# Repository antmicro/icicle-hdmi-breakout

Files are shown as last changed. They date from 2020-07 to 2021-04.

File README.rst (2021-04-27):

====================
Icicle HDMI breakout
====================

Copyright (c) 2020 `Antmicro <https://www.antmicro.com>`_

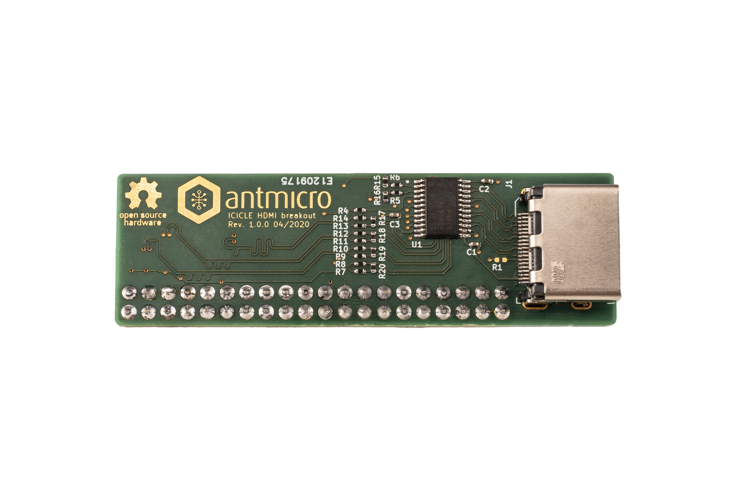
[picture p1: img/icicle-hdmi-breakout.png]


Overview
========

This repository contains open hardware design files for Antmicro's expansion board compatible with the `PolarFire SoC FPGA Icicle Evaluation Kit from Microchip. <https://www.microsemi.com/existing-parts/parts/152514>`_.
The design files were created in KiCad.
The expansion board breaks out an HDMI interface on a regular HDMI connector.
The TMDS data going out of this connector are connected to the FPGA fabric in `MPFS250T-FCVG484EES <https://www.microsemi.com/document-portal/doc_download/1244583-polarfire-soc-advance-datasheet>`_ PolarFire SoC.
The expansion board should be connected to the ``J26`` expansion connector on the Icicle board.
For more information regarding the electrical connections please refer to the schematic sheets and compare them against the `offcial documentation <https://www.microsemi.com/product-directory/soc-fpgas/5498-polarfire-soc-fpga#resources>`_ of the PolarFire Icicle kit.

Repository structure
--------------------

The main repository directory contains KiCad PCB project files, LICENSE and README.
The remaining files are stored in the following directories:

* ``3d-model`` - contains a `mechanical model <3d-model/icicle-hdmi-breakout.stl>`_ of the board in the stl mesh format
* ``lib`` - contains the component libraries
* ``doc`` - contains selected files for device fabrication (schematic in PDF, BoM)
* ``img`` - contains graphics for this README

Dimensions and layout
=====================

The image below presents the HDMI expansion board's dimensions and layout.

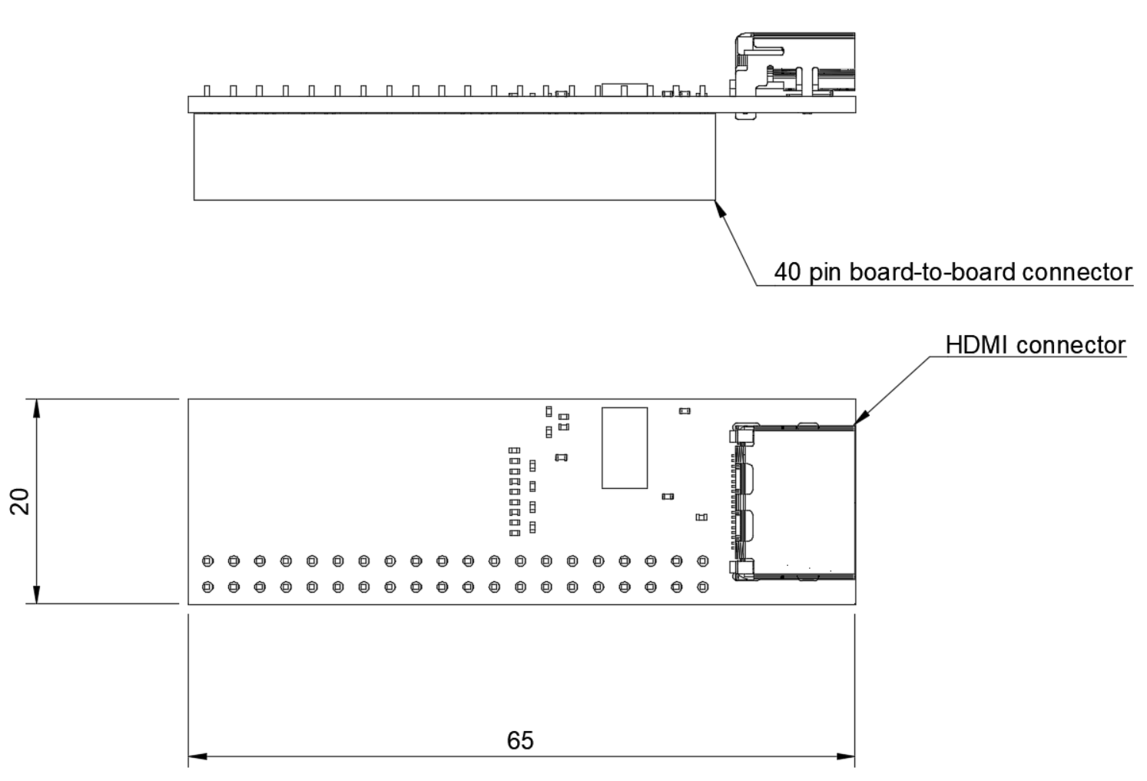
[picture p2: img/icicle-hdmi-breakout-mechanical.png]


License
=======

`MIT <LICENSE>`_

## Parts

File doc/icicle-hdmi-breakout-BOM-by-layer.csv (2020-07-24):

Reference | Quantity | Value | Footprint | Manufacturer | MPN | Layer
C1 C2 C3 | 3 | C_100n_0402_16V | 0402-cap | MULTICOMP | MC0402B104K160CT | Top
J1 | 1 | 685119134923 | HDMI_A_Female_685119134923 | Amphenol | 685119134923 | Top
R15 R16 | 2 | R_10k_0402 | 0402-res | VISHAY | CRCW040210K0FKEDHP | Top
R17 R18 R19 R20 | 4 | R_100R_0402 | 0402-res | BOURNS | CR0402-FX-1000GLF | Top
R4 R5 R6 R7 R8 R9 R10 R11 R12 R13 R14 | 11 | R_0R_0402 | 0402-res | PANASONIC | ERJ2GE0R00X | Top
U1 | 1 | TPD12S016PWR | TPD12S016PWR | Texas Instruments | TPD8S009DSMR | Top
J2 | 1 | 2x20_Header_Female | PinHeader_2x40_P2.54_Drill1mm | MULTICOMP | 2214S-40SG-85 | Bottom
R2 R3 | 2 | R_0R_0402 | 0402-res | PANASONIC | ERJ2GE0R00X | Bottom
R1 R21 R22 R23 R24 R25 R26 R27 R28 | 9 | R_10k_0402 | 0402-res | VISHAY | CRCW040210K0FKEDHP | DNP
N1 | 1 | antmicro_logo | antmicro-logo |  |  | Virtual
N2 | 1 | oshw_logo | oshw-logo |  |  | Virtual

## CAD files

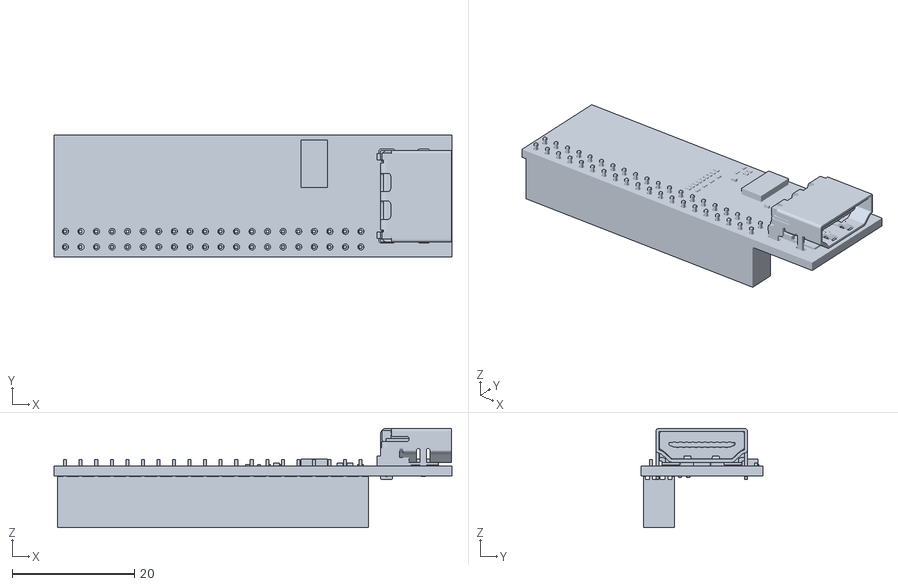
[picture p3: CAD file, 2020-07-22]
3d-model/icicle-hdmi-breakout.stl
65.0 x 20.0 x 16.2

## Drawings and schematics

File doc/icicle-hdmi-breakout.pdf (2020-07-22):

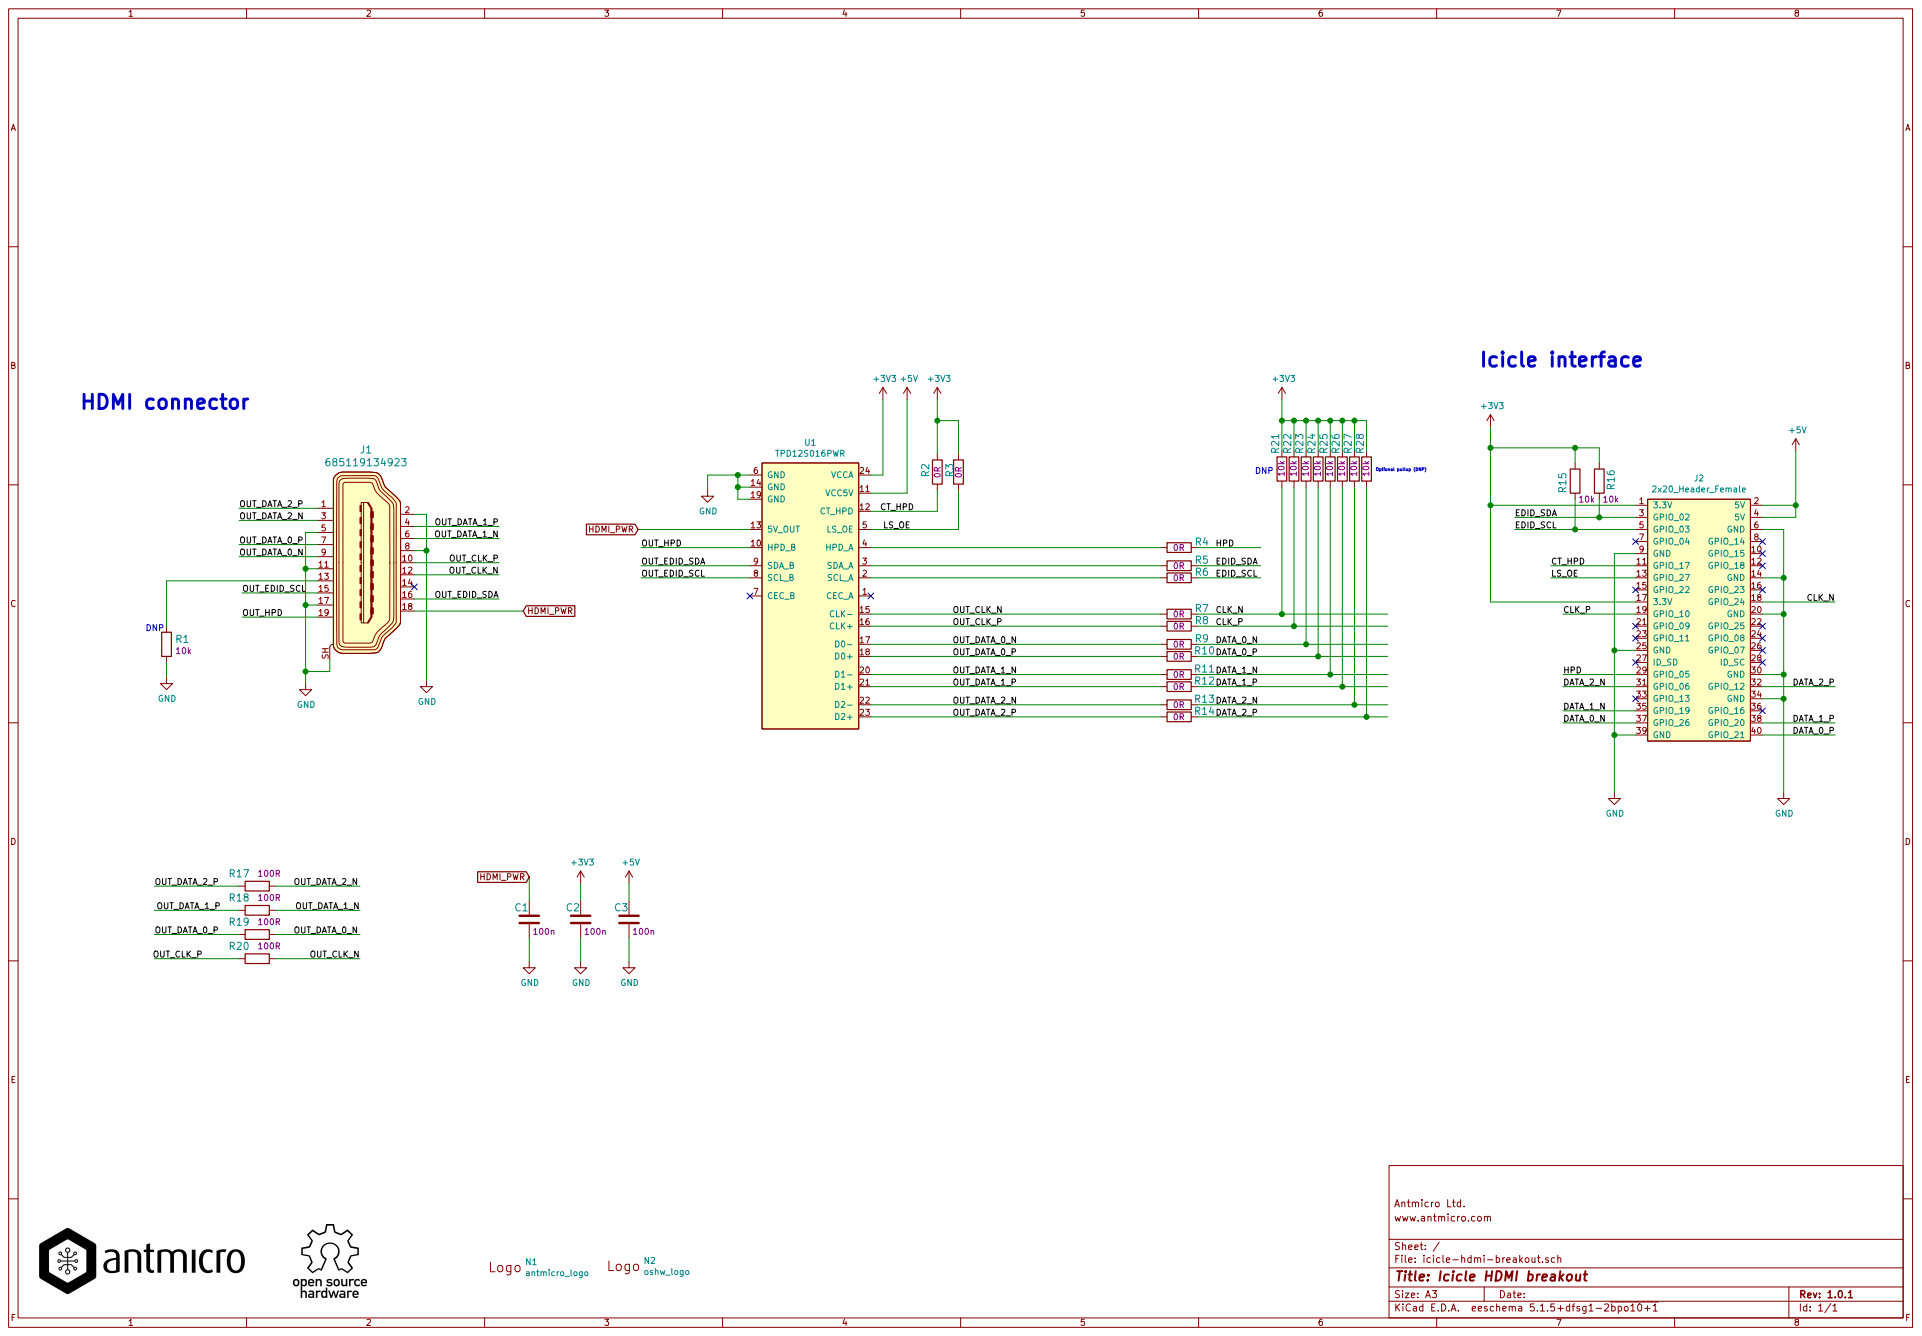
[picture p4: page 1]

Antmicro Ltd.
Id: 1/1 Title: Icicle HDMI breakout File: icicle-hdmi-breakout.sch Sheet: / www.antmicro.com

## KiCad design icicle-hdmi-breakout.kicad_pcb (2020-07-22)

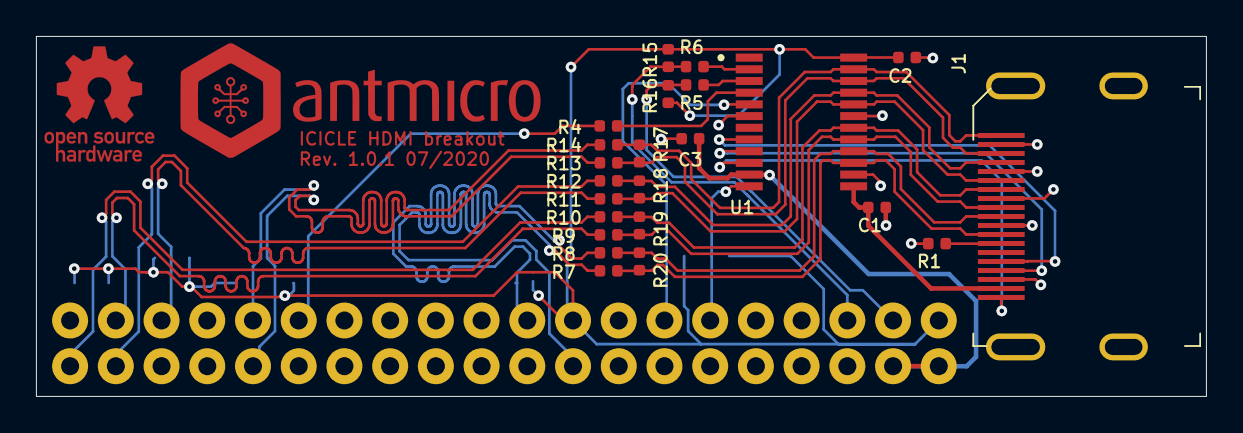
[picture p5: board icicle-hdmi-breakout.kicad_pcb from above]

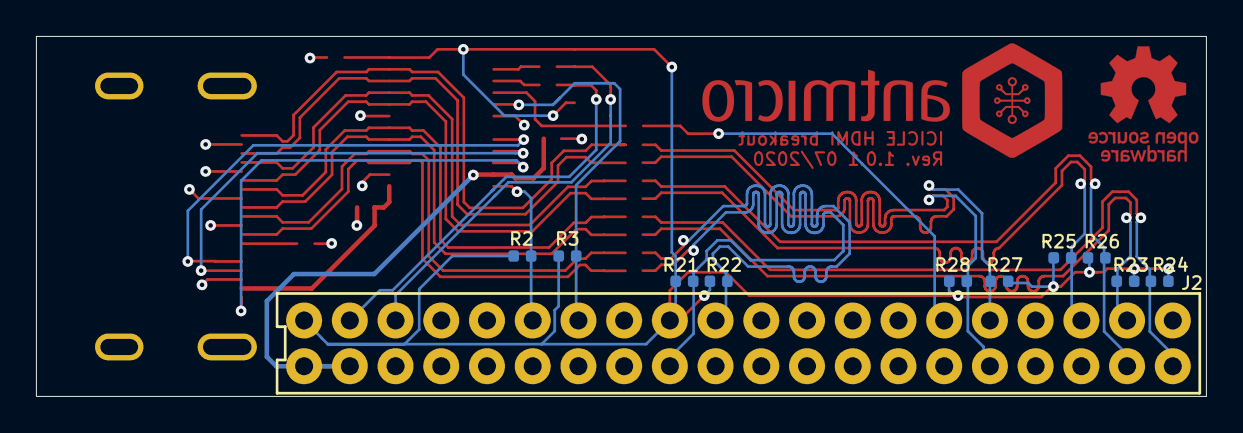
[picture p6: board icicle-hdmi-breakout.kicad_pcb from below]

Board: 4 copper layers, 65.0 x 20.0 mm, 36 parts (11 on the bottom side), 32 nets.

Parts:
C1, C2, C3: C_100n_0402_16V; 0402-cap
J1: 685119134923; HDMI_A_Female_685119134923
J2: 2x20_Header_Female; PinHeader_2x40_P2.54_Drill1mm
N1: antmicro_logo; antmicro-logo_scaled_20mm
N2: oshw_logo; oshw-logo
R1, R15, R16, R21, R22, R23, R24, R25, R26, R27, R28: R_10k_0402; 0402-res
R2, R3, R4, R5, R6, R7, R8, R9, R10, R11, R12, R13, R14: R_0R_0402; 0402-res
R17, R18, R19, R20: R_100R_0402; 0402-res
U1: TPD12S016PWR

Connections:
+3V3: C2.1, J2.1, J2.17, R2.1, R3.1, R15.1, R16.1, R21.1, R22.1, R23.1, R24.1, R25.1, R26.1, R27.1, R28.1, U1.24
+5V: C3.1, J2.2, J2.4, U1.11
/CLK_N: J2.18, R7.1, R21.2
/CLK_P: J2.19, R8.1, R22.2
/CT_HPD: J2.11, R2.2, U1.12
/DATA_0_N: J2.37, R9.1, R23.2
/DATA_0_P: J2.40, R10.1, R24.2
/DATA_1_N: J2.35, R11.1, R25.2
/DATA_1_P: J2.38, R12.1, R26.2
/DATA_2_N: J2.31, R13.1, R27.2
/DATA_2_P: J2.32, R14.1, R28.2
/EDID_SCL: J2.5, R6.1, R15.2
/EDID_SDA: J2.3, R5.1, R16.2
/HPD: J2.29, R4.1
/LS_OE: J2.13, R3.2, U1.5
/OUT_CLK_N: J1.12, R7.2, R20.1, U1.15
/OUT_CLK_P: J1.10, R8.2, R20.2, U1.16
/OUT_DATA_0_N: J1.9, R9.2, R19.1, U1.17
/OUT_DATA_0_P: J1.7, R10.2, R19.2, U1.18
/OUT_DATA_1_N: J1.6, R11.2, R18.1, U1.20
/OUT_DATA_1_P: J1.4, R12.2, R18.2, U1.21
/OUT_DATA_2_N: J1.3, R13.2, R17.1, U1.22
/OUT_DATA_2_P: J1.1, R14.2, R17.2, U1.23
/OUT_EDID_SCL: J1.15, U1.8
/OUT_EDID_SDA: J1.16, U1.9
/OUT_HPD: J1.19, U1.10
GND: C1.2, C2.2, C3.2, J1.2, J1.5, J1.8, J1.11, J1.17, J1.SH, J2.6, J2.9, J2.14, J2.20, J2.25, J2.30, J2.34, J2.39, R1.2, U1.6, U1.14, U1.19
HDMI_PWR: C1.1, J1.18, U1.13
unnamed: J1.13, R1.1
unnamed: R4.2, U1.4
unnamed: R5.2, U1.3
unnamed: R6.2, U1.2

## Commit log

2020-07-22 Add release 1.0.1
    [icicle-hdmi-breakout.kicad_pcb, icicle-hdmi-breakout.sch, icicle-hdmi-breakout.stl]
2020-07-24 Add BOM
    [icicle-hdmi-breakout-BOM-by-layer.csv, icicle-hdmi-breakout-BOM-populated.csv]
